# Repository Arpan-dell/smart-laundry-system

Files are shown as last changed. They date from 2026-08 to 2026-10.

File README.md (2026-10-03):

# Smart Laundry Auto-Ordering System

An ESP32-based smart laundry basket that weighs your laundry and automatically sends a pickup order to the laundry manager over Telegram once the basket is full.

> **Status: Phase 1 (working prototype).** The core loop works end to end: weigh, display, auto-order and remind. Planned Phase 2 improvements are listed under [Roadmap](#roadmap-phase-2).

## How It Works

1. **Weighing:** a load cell under the basket, read through an HX711 amplifier, measures the weight of the laundry continuously. Readings are smoothed so the display stays steady but still reacts instantly to large changes.
2. **Display:** a 0.96" SSD1306 OLED shows the live weight, a progress bar towards the target weight, the Wi-Fi signal and the battery level.
3. **Auto-order:** when the weight stays at or above the target (default **5 kg**) for **3 seconds**, the ESP32 sends a pickup request to the laundry manager's Telegram chat:
   ```
   Smart Laundry Alert
   Order ID: #ORD-12345
   Total Weight: 5.12 kg
   Request Time: 04-Oct-2026 06:30 PM
   Pickup Address: <your address>
   ```
   The 3-second hold stops a quick bump or press on the lid from triggering an order.
4. **One order per load:** after an order is sent, the system latches so it doesn't send again. If the basket is still full **24 hours** later, it sends a single `[REMINDER]` message.
5. **Reset:** when the basket is emptied (under 1 kg for 5 seconds), the latch resets, ready for the next load.
6. **Local alert:** a red LED blinks whenever the weight is over the target.

### Boot sequence

On power-up the device shows a splash screen, reconnects to the last Wi-Fi network it joined (12-second timeout), syncs the clock over NTP (IST) so orders carry a real timestamp, then wakes and zeroes the load cell. If Wi-Fi fails, the scale and menu still work offline.

### On-device menu

Press **OK** on the main screen to open the menu. Use **UP/DOWN** to move and **OK** to select.

| Menu item | What it does |
|---|---|
| Tare Scale | Zeroes the scale (empty basket) |
| Set Target | Changes the order threshold in 0.5 kg steps |
| Customer Order | Sends a pickup order manually, with confirmation |
| Calibrate Scale | Two-step calibration: empty the basket and press OK, then place a known weight, set its value with UP/DOWN and press OK. The result is saved to flash |
| Scan WiFi | Scans for nearby networks and connects to the one you pick (see below) |
| Battery Info | Shows the battery percentage |
| Exit Menu | Returns to the main screen |

### Wi-Fi scanning

**Scan WiFi** lists the networks in range. You can connect to:
- any **open** network, or
- any **secured** network whose password is saved in the firmware's `KNOWN_NETWORKS` list.

Secured networks without a saved password are marked with `*`. The ESP32 remembers the last network it joined and reconnects to it on the next boot.

## Engineering Notes

Problems solved while building Phase 1:

- **Wi-Fi start-up resets:** Wi-Fi start-up draws a burst of current that sagged the battery rail and tripped the ESP32's brownout reset. The firmware disables the brownout detector and powers up peripherals in stages.
- **Late HX711 wake-up:** at low supply voltage the HX711 sometimes isn't ready at boot, so it can't be zeroed. The firmware remembers that it still needs zeroing and does it the moment the sensor responds, so a large fake weight never appears.
- **Button-press spikes:** pressing a button on the enclosure physically loads the scale. Weight updates pause for 1.5 seconds after menu actions, so a press can't cause a false reading or an accidental order.
- **Stable readings:** exponential smoothing removes jitter, large changes (basket lifted or loaded) snap through instantly, and anything under 50 g reads as 0.00 kg.
- **Button debouncing:** edge detection plus a 250 ms lockout on each button stops a single press registering twice.

## Hardware

| Component | Purpose |
|---|---|
| ESP32 Dev Board | Main controller, Wi-Fi |
| Load Cell (5/10 kg) + HX711 | Weight sensing |
| 0.96" SSD1306 OLED (I2C) | Live weight and menu UI |
| 3 × Tactile Buttons | UP / OK / DOWN navigation |
| Red LED | Over-target indicator |
| 3.7 V Li-ion + TP4056 (or USB power) | Power |
| 3D-printed enclosure | Designed in Tinkercad (see [`cad/`](cad/)) |

Full pinout and wiring: [`circuit/wiring.md`](circuit/wiring.md). Block diagram: [`circuit/block_diagram.md`](circuit/block_diagram.md).

## Repository Structure

| Folder | Contents |
|---|---|
| [`code/laundry_system/`](code/laundry_system/) | ESP32 firmware (`laundry_system.ino`, `secrets.example.h`) |
| [`circuit/`](circuit/) | Circuit diagram, wiring table, block diagram |
| [`cad/`](cad/) | Enclosure STL files and renders |
| [`photos/`](photos/) | Photos of the build |
| [`videos/`](videos/) | Demo videos |

## Getting Started

1. Wire the components as described in [`circuit/wiring.md`](circuit/wiring.md).
2. In the Arduino IDE, install the libraries **HX711**, **Adafruit SSD1306** and **Adafruit GFX**. (WiFi and HTTPClient come with the ESP32 board package.)
3. In [`code/laundry_system/`](code/laundry_system/), **fill in your own details**:
   - Copy `secrets.example.h` to `secrets.h` and set the Telegram bot token (from @BotFather), the laundry manager's chat ID and the pickup address. `secrets.h` is git-ignored.
   - In `laundry_system.ino`, add your Wi-Fi networks to `KNOWN_NETWORKS`:
     ```cpp
     const KnownNetwork KNOWN_NETWORKS[] = {
       {"YOUR_WIFI_SSID_1", "YOUR_WIFI_PASSWORD_1"},
       {"YOUR_WIFI_SSID_2", "YOUR_WIFI_PASSWORD_2"}
     };
     ```
   > Never commit your real credentials to a public repository.
4. Open `laundry_system.ino` in the Arduino IDE, select your ESP32 board and port, and upload.
5. On the device, use **Scan WiFi** to join a network, then **Calibrate Scale** with a known weight.

## Gallery

### Photos

| | |
|---|---|
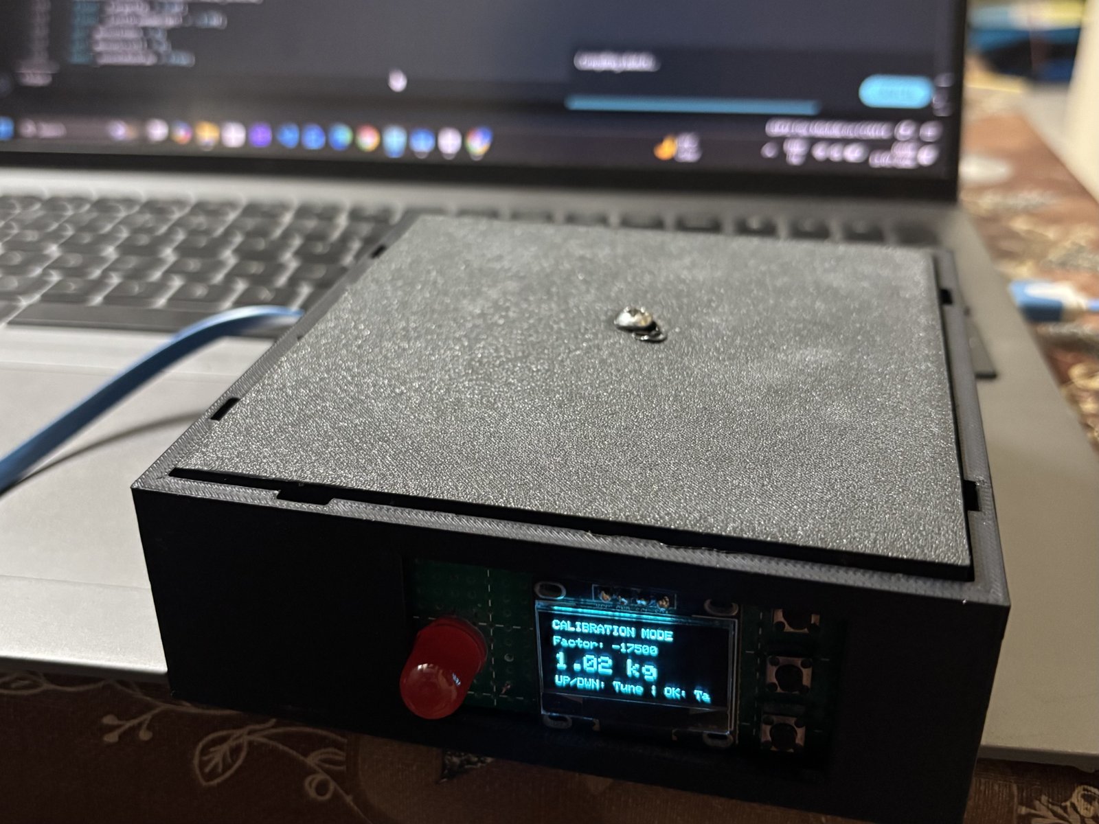
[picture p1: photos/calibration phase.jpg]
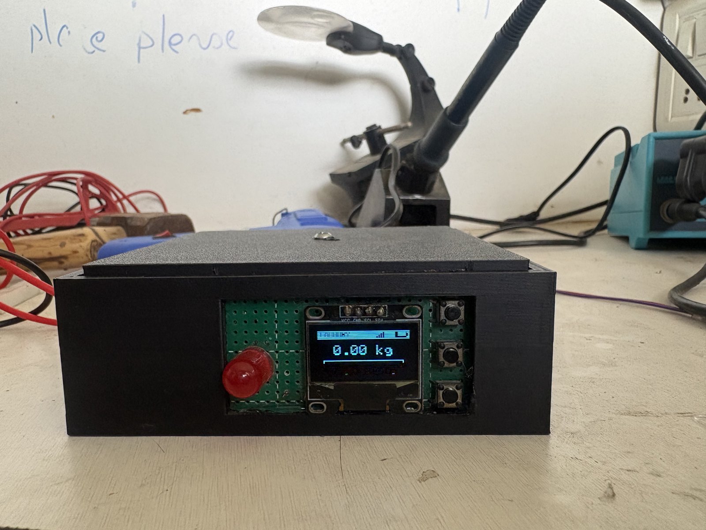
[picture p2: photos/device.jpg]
| <br>**calibration phase** | <br>**device** |
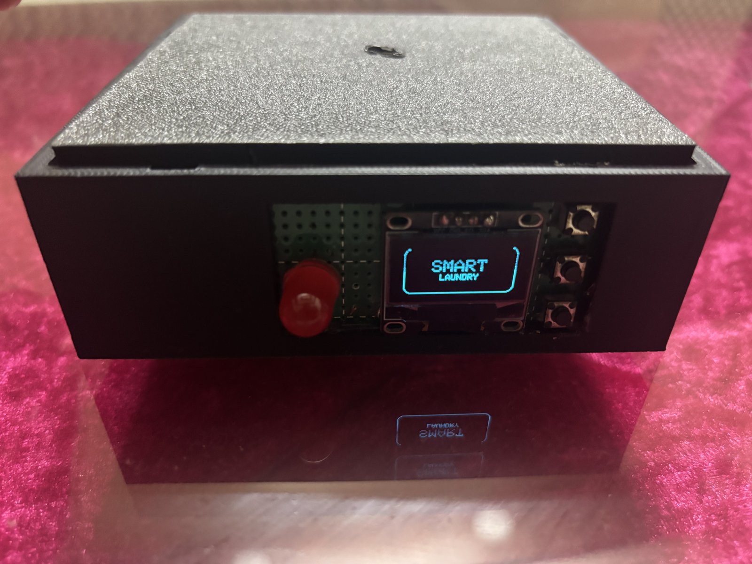
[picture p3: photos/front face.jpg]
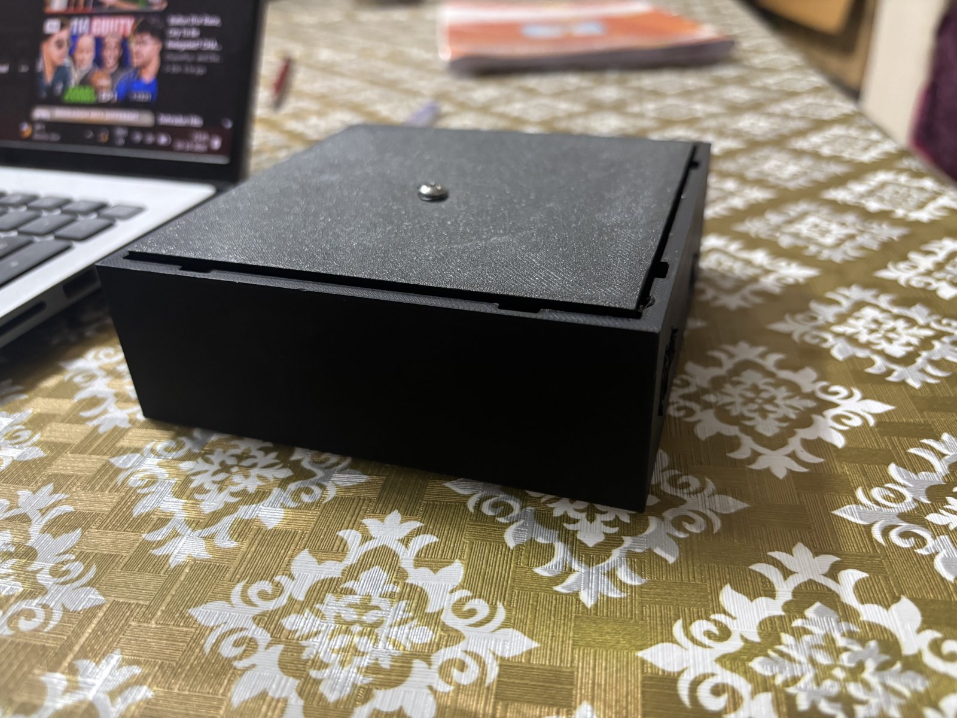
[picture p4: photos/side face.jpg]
| <br>**front face** | <br>**side face** |

### Videos

- [connecting to wifi](videos/connecting%20to%20wifi.mp4)
- [custom order](videos/custom%20order.mp4)
- [menu](videos/menu.mp4)
- [weight verification](videos/weight%20verification.mp4)

## Roadmap (Phase 2)

- [ ] Enter Wi-Fi passwords from a phone (captive portal) instead of saving them in the firmware
- [ ] Save the target weight to flash so it survives a reboot
- [ ] Deep sleep with button/timer wake-up for longer battery life
- [ ] Accurate battery measurement through a calibrated voltage divider
- [ ] Two-way Telegram: confirm or cancel an order from the phone
- [ ] Verified TLS for API calls
- [ ] Custom PCB to replace the perfboard

## Author

**Arpan Ailawadi**
B.Tech, Electronics and Communication Engineering, Delhi Technological University
[LinkedIn](https://www.linkedin.com/in/arpan-ailawadi/)

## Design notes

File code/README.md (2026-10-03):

# Firmware

ESP32 firmware for the Smart Laundry Auto-Ordering System, developed in the Arduino IDE.

## Files

| File | Description |
|---|---|
| `laundry_system/laundry_system.ino` | Main firmware: OLED menu UI, HX711 weighing and calibration, Wi-Fi scanning, threshold auto-orders and Telegram/NTP |
| `laundry_system/secrets.example.h` | Template for the Telegram token, chat ID and pickup address |

## Setup

1. Copy `laundry_system/secrets.example.h` to `laundry_system/secrets.h` and fill in your values (`secrets.h` is git-ignored).
2. Add your Wi-Fi networks to `KNOWN_NETWORKS` at the top of `laundry_system.ino`.
3. Install the required libraries: HX711, Adafruit SSD1306 and Adafruit GFX. WiFi, HTTPClient and Preferences come with the ESP32 board package.
4. Open `laundry_system/laundry_system.ino` in the Arduino IDE, select your ESP32 board and port, then upload.

See [`../circuit/wiring.md`](../circuit/wiring.md) for pin connections.

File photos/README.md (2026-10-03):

# Photos

- [calibration phase](calibration%20phase.jpg)
- [device](device.jpg)
- [front face](front%20face.jpg)
- [side face](side%20face.jpg)

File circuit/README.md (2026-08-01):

# Circuit Documentation

Wiring schematic and system architecture for the Smart Laundry Auto-Ordering System.

## Files

| File | Description |
|---|---|
| `wiring.md` | Full pinout table and step-by-step wiring instructions for the ESP32, HX711 load cell, SSD1306 OLED, and tactile buttons |
| `block_diagram.md` | System block diagram (Mermaid flowchart) showing power, sensing, input, output, and connectivity paths |
| `circuit_diagram.png` | Visual circuit diagram |

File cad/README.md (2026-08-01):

# Enclosure CAD Files

3D-printable enclosure for the Smart Laundry Auto-Ordering System, designed in Tinkercad. The enclosure is split into two printable halves.

## Files

| Folder | Contents | Description |
|---|---|---|
| `bottom/` | `bottom.stl`, `bottom_render1.png`, `bottom_render2.png` | Bottom half of the enclosure — houses the ESP32, HX711, and load cell mount |
| `top/` | `top.stl`, `top_render.png` | Top half of the enclosure — cutouts for the OLED display window and tactile buttons |

## Notes

- Files are provided in `.stl` format, ready for slicing and 3D printing.
- Renders (`.png`) show the design from Tinkercad for quick preview without opening a CAD tool.
- Designed in [Tinkercad](https://www.tinkercad.com/).

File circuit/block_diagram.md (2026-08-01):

# System Block Diagram

```mermaid
flowchart TD
    subgraph Power["Power Supply"]
        BAT["3.7V Li-ion Battery"] --> TP["TP4056 Charger"]
        TP --> ESP32
        USB["USB Power Bank"] -.-> ESP32
    end

    subgraph Sensing["Sensing"]
        LC["Load Cell (5kg/10kg)"] --> HX["HX711 Amplifier"]
        HX -->|DOUT / SCK| ESP32
    end

    subgraph Input["User Input"]
        UP["UP Button"] --> ESP32
        OK["OK Button"] --> ESP32
        DOWN["DOWN Button"] --> ESP32
    end

    ESP32["ESP32 Dev Board"]

    subgraph Output["Display & Alerts"]
        ESP32 -->|I2C: SDA/SCL| OLED["SSD1306 OLED Display"]
        ESP32 -->|Optional| LED["Red LED"]
    end

    subgraph Connectivity["Connectivity"]
        ESP32 -->|Wi-Fi| WIFI["Wi-Fi Network"]
        WIFI --> NTP["NTP Time Sync"]
        WIFI --> TG["Telegram Bot API"]
        TG --> USER["User's Phone (Alert)"]
    end
```

## How it works

1. **Power** — the battery feeds the ESP32 through the TP4056 charger (or USB power directly).
2. **Sensing** — the load cell measures weight, and the HX711 amplifies and digitizes that reading for the ESP32.
3. **Input** — three tactile buttons let the user navigate the on-device menu.
4. **Output** — the ESP32 drives the OLED display for status/menu, and optionally triggers a red LED for local alerts.
5. **Connectivity** — when the weight crosses a threshold, the ESP32 connects to Wi-Fi, syncs time via NTP, and sends a Telegram alert to the user's phone.

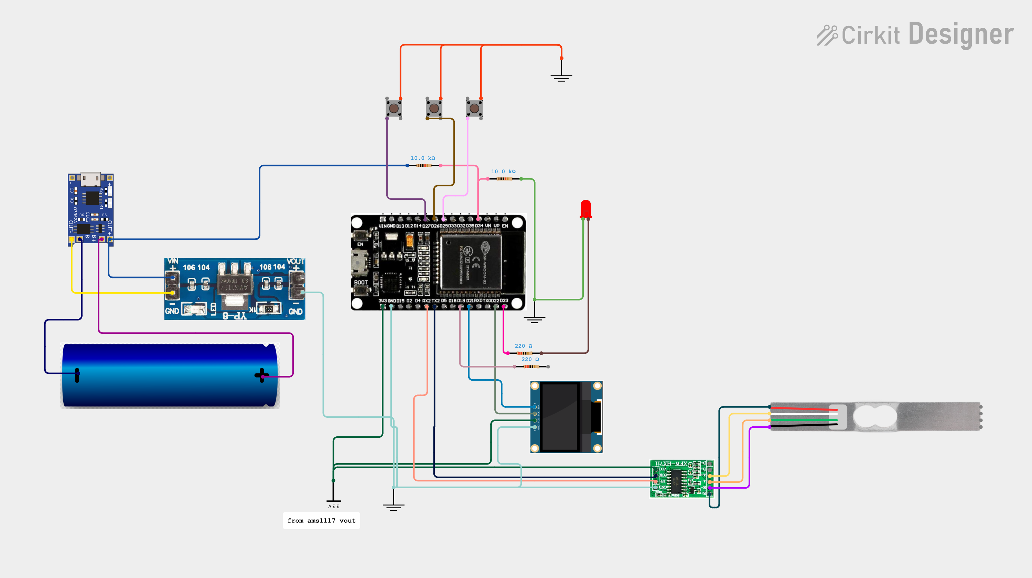
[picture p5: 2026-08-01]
circuit_diagram.png

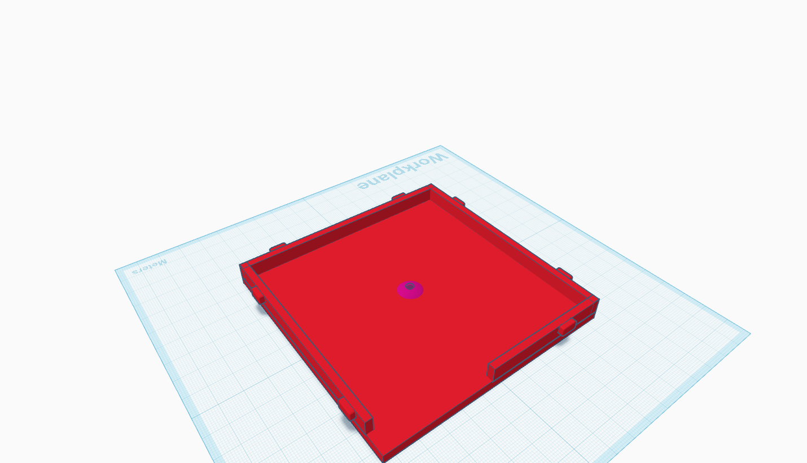
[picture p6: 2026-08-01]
cad/top/top_render.png

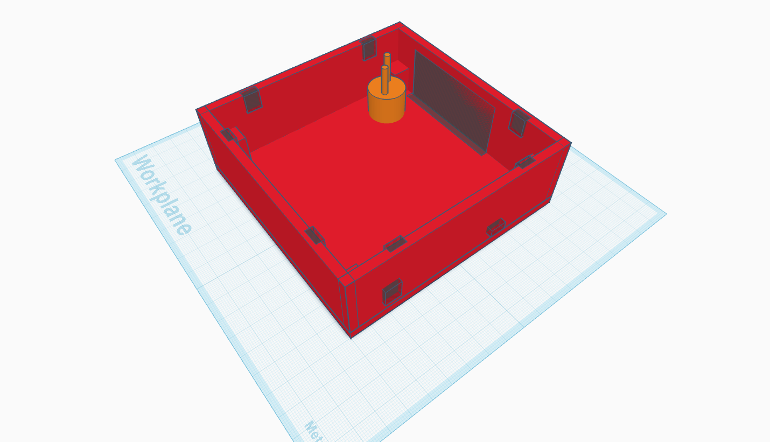
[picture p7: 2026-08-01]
cad/bottom/bottom_render2.png

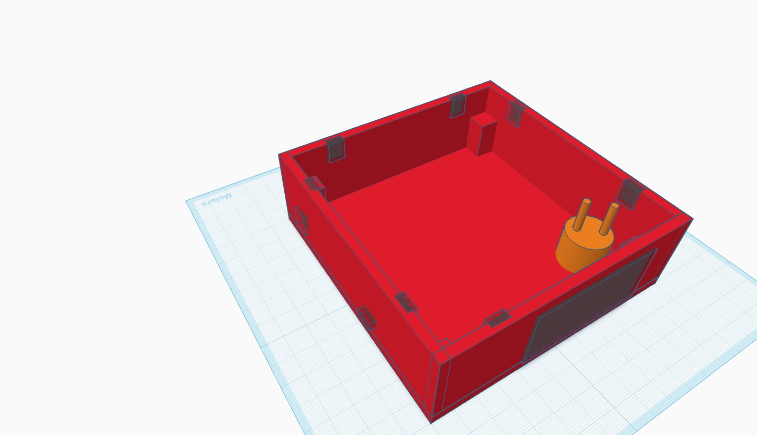
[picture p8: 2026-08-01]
cad/bottom/bottom_render1.png

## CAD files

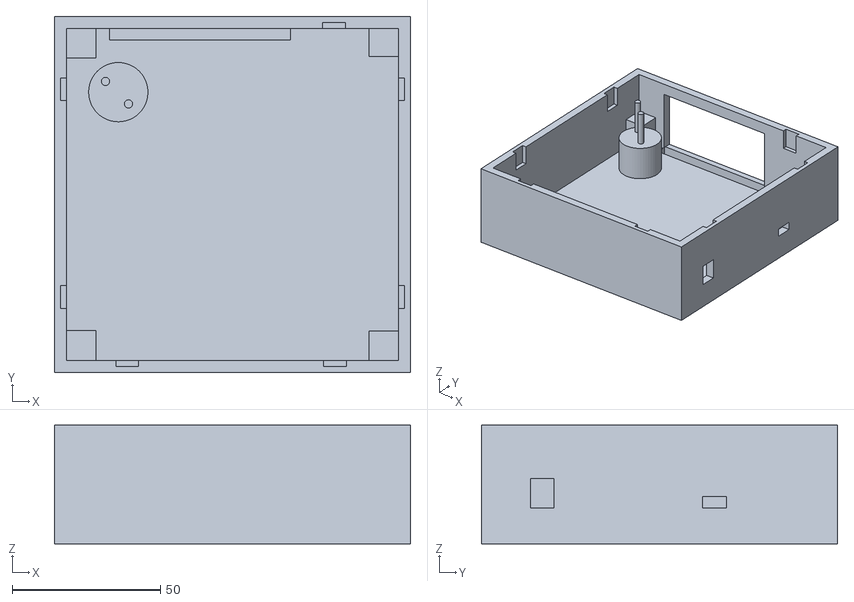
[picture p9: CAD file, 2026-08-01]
cad/bottom/bottom.stl
120.0 x 120.0 x 40.0

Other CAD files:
cad/top/top.stl

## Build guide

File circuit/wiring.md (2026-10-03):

# Wiring / Pin Connections

Complete wiring schematic and component list for the Smart Laundry Auto-Ordering System.

## Components

| Component | Spec |
|---|---|
| Microcontroller | ESP32 Development Board |
| Display | 0.96" SSD1306 OLED (I2C) |
| Weight Sensor | 5kg/10kg Load Cell + HX711 Amplifier |
| Input | 3x Tactile Push Buttons (UP, OK, DOWN) |
| Power Source | 3.7V Lithium Battery via TP4056 Charger (or USB Power Bank) |
| Optional Alert | Red LED |

## Master Pinout Table

| ESP32 Pin | Component | Description / Function |
|---|---|---|
| VIN (or 5V) | Power Source | Connects to Battery OUT+ (via TP4056) or USB power |
| 3V3 | OLED & HX711 | Powers OLED VCC and HX711 VCC (3.3V out) |
| GND | All Components | Common ground for the entire circuit |
| D21 | OLED (SDA) | I2C serial data for the display |
| D22 | OLED (SCL) | I2C serial clock for the display |
| D32 | HX711 (DOUT) | Serial data from the load cell amplifier |
| D33 | HX711 (SCK) | Serial clock to pulse the load cell amplifier |
| D25 | Button (UP) | Tactile button, wired to GND, internal pull-up |
| D26 | Button (OK) | Tactile button, wired to GND, internal pull-up |
| D27 | Button (DOWN) | Tactile button, wired to GND, internal pull-up |
| D34 | Battery Sensor | Reads battery voltage (requires 10k/10k voltage divider) |
| D23 | LED (Optional) | Triggers red threshold warning LED |

## Wiring Instructions

### 1. Power Distribution
- TP4056 `OUT+` → ESP32 `VIN` (or `5V`)
- TP4056 `OUT-` → ESP32 `GND`
- ESP32 `3V3` → OLED `VCC` and HX711 `VCC`/`VDD`

> **Note:** If using the "direct bypass" approach due to a weak battery, the OLED VCC, HX711 VCC, and ESP32 3V3 are all wired directly to TP4056 `OUT+`.

### 2. HX711 Load Cell Amplifier
- `VCC`/`VDD` → ESP32 `3V3`
- `GND` → ESP32 `GND`
- `DOUT` → ESP32 `D32`
- `SCK` → ESP32 `D33`
- Load cell 4-wire (Red, Black, White, Green) → HX711 `E+`, `E-`, `A-`, `A+` respectively

### 3. SSD1306 OLED Display
- `VCC` → ESP32 `3V3`
- `GND` → ESP32 `GND`
- `SDA` → ESP32 `D21`
- `SCL` → ESP32 `D22`

### 4. Push Buttons (Menu Controls)
- **UP:** one leg → `D25`, other leg → `GND`
- **OK:** one leg → `D26`, other leg → `GND`
- **DOWN:** one leg → `D27`, other leg → `GND`

No external resistors needed — firmware enables the ESP32's internal pull-up resistors.

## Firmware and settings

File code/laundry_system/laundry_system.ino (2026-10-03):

// ============================================================================
// SMART LAUNDRY AUTO-ORDERING SYSTEM - Phase 1
// Weighs the laundry basket with an HX711 load cell, shows live weight and a
// 3-button menu on an SSD1306 OLED, and sends a pickup order to the laundry
// manager on Telegram once the basket stays above the target weight.
// ============================================================================

#include <WiFi.h>
#include "secrets.h" // tokens, passwords, private URLs: copy secrets.example.h to secrets.h
#include <Wire.h>
#include <Adafruit_GFX.h>
#include <Adafruit_SSD1306.h>
#include "HX711.h"
#include <Preferences.h>
#include "soc/soc.h"
#include "soc/rtc_cntl_reg.h"

// ---------------- Config ----------------
#define REMINDER_DELAY_MS  86400000UL // 24 hours before reminder is sent

// >>> FILL THESE IN FOR YOUR OWN SETUP before uploading <<<
// Wi-Fi networks the device may join from the "Scan WiFi" menu.
// Open networks need no entry; secured networks must be listed here.
// Telegram token, chat ID and pickup address go in secrets.h
// (copy secrets.example.h to secrets.h). Never commit real values.
struct KnownNetwork {
  const char* ssid;
  const char* pass;
};
const KnownNetwork KNOWN_NETWORKS[] = {
  {"YOUR_WIFI_SSID_1", "YOUR_WIFI_PASSWORD_1"},
  {"YOUR_WIFI_SSID_2", "YOUR_WIFI_PASSWORD_2"}
};
const int NUM_KNOWN_NETWORKS = sizeof(KNOWN_NETWORKS) / sizeof(KnownNetwork);

#define NTP_SERVER          "pool.ntp.org"
#define GMT_OFFSET_SEC       (5 * 3600 + 1800)  
#define DAYLIGHT_OFFSET_SEC  0
#define SCREEN_WIDTH  128
#define SCREEN_HEIGHT 64
#define OLED_RESET    -1
#define I2C_SDA       21
#define I2C_SCL       22
#define OLED_I2C_ADDR 0x3C

#define LOADCELL_DOUT_PIN 32
#define LOADCELL_SCK_PIN  33
#define LOADCELL_CALIBRATION_FACTOR -30616.0f

#define BTN_UP_PIN   25
#define BTN_OK_PIN   26
#define BTN_DOWN_PIN 27

#define BATT_PIN     34
#define BATT_RAW_MIN 1980
#define BATT_RAW_MAX 2600

#define LED_RED_PIN 23   

#define DEFAULT_TARGET_KG 5.0f

class ButtonManager {
public:
  struct Presses {
    bool up, ok, down;
    bool any() const { return up || ok || down; }
  };

  void begin(uint8_t upPin, uint8_t okPin, uint8_t downPin) {
    _upPin = upPin;
    _okPin = okPin;
    _downPin = downPin;
    pinMode(_upPin, INPUT_PULLUP);
    pinMode(_okPin, INPUT_PULLUP);
    pinMode(_downPin, INPUT_PULLUP);
  }

  Presses poll() {
    Presses p = {false, false, false};
    unsigned long now = millis();

    // Check UP (250ms debounce to prevent double-clicks from cheap springs)
    bool upState = digitalRead(_upPin) == LOW;
    if (upState && !_lastUpState && now - _lastUpTime > 250) {
      p.up = true; _lastUpTime = now;
    }
    _lastUpState = upState;

    // Check OK
    bool okState = digitalRead(_okPin) == LOW;
    if (okState && !_lastOkState && now - _lastOkTime > 250) {
      p.ok = true; _lastOkTime = now;
    }
    _lastOkState = okState;

    // Check DOWN
    bool downState = digitalRead(_downPin) == LOW;
    if (downState && !_lastDownState && now - _lastDownTime > 250) {
      p.down = true; _lastDownTime = now;
    }
    _lastDownState = downState;

    return p;
  }

private:
  uint8_t _upPin = 0, _okPin = 0, _downPin = 0;
  bool _lastUpState = false, _lastOkState = false, _lastDownState = false;
  unsigned long _lastUpTime = 0, _lastOkTime = 0, _lastDownTime = 0;
};


// ---------------- BatteryMonitor ----------------
class BatteryMonitor {
public:
  void begin(uint8_t pin) { 
    _pin = pin; 
    _smoothedPct = -1; 
  }
  
  int readPercentage() {
    // Take an average of 20 samples to filter out Wi-Fi electrical noise
    long sum = 0;
    for (int i = 0; i < 20; i++) {
      sum += analogRead(_pin);
    }
    int raw = sum / 20;
    
    int pct = map(raw, BATT_RAW_MIN, BATT_RAW_MAX, 0, 100);
    pct = constrain(pct, 0, 100);
    
    // Smooth the percentage so it doesn't jump randomly between redraws
    if (_smoothedPct == -1) {
      _smoothedPct = pct;
    } else {
      _smoothedPct = (_smoothedPct * 9 + pct) / 10;
    }
    
    return _smoothedPct;
  }
private:
  uint8_t _pin = 0;
  int _smoothedPct = -1;
};


// ---------------- DisplayManager ----------------
class DisplayManager {
public:
  bool begin() {
    Wire.begin(I2C_SDA, I2C_SCL);
    bool ok = _display.begin(SSD1306_SWITCHCAPVCC, OLED_I2C_ADDR);
    if (!ok) {
      delay(500);
      ok = _display.begin(SSD1306_SWITCHCAPVCC, OLED_I2C_ADDR);
    }
    Wire.setClock(100000);
    _display.setTextColor(SSD1306_WHITE);
    _display.cp437(true);
    return ok;
  }

  void showBootScreen(const char* title, const char* subtitle) {
    _display.clearDisplay();
    _display.drawRoundRect(4, 4, SCREEN_WIDTH - 8, SCREEN_HEIGHT - 8, 8, SSD1306_WHITE);
    printCentered(title, 18, 2);
    printCentered(subtitle, 36, 1);
    _display.display();
  }

  void showStatusLine(const char* line1, const char* line2, int dots) {
    _display.clearDisplay();
    printCentered(line1, 10, 1);
    printCentered(line2, 22, 1);
    for (int i = 0; i < dots && i < 6; i++) {
      _display.setCursor(10 + i * 8, 40);
      _display.print(".");
    }
    _display.display();
  }

  void showToast(const char* msg, uint16_t holdMs = 800) {
    _display.clearDisplay();
    printCentered(msg, 24, 2);
    _display.display();
    delay(holdMs);
  }

  void drawMainScreen(float weightKg, float targetKg, int batteryPct, int wifiBars) {
    _display.clearDisplay();
    drawHeader(batteryPct, wifiBars);
    char buf[16];
    dtostrf(weightKg, 4, 2, buf);
    String weightStr = String(buf) + " kg";
    printCentered(weightStr.c_str(), 20, 2);
    drawTargetBar(weightKg, targetKg, 42, 10);
    _display.display();
  }

  void drawMenuList(const char* const* items, int count, int selectedIndex, int scrollOffset) {
    _display.clearDisplay();
    printCentered("MENU", 0, 1);
    _display.drawLine(0, 10, SCREEN_WIDTH, 10, SSD1306_WHITE);

    const int visibleRows = 3;
    for (int row = 0; row < visibleRows; row++) {
      int itemIdx = scrollOffset + row;
      if (itemIdx >= count) break;
      int y = 14 + row * 16;
      bool selected = (itemIdx == selectedIndex);

      if (selected) {
        _display.fillRect(0, y - 1, SCREEN_WIDTH, 14, SSD1306_WHITE);
        _display.setTextColor(SSD1306_BLACK);
      } else {
        _display.setTextColor(SSD1306_WHITE);
      }
      _display.setTextSize(1);
      _display.setCursor(6, y + 3);
      _display.print(items[itemIdx]);
    }
    _display.setTextColor(SSD1306_WHITE);
    _display.display();
  }

  void drawEditThreshold(float targetKg) {
    _display.clearDisplay();
    printCentered("SET TARGET", 2, 1);
    char buf[16];
    dtostrf(targetKg, 4, 2, buf);
    String s = String(buf) + " kg";
    printCentered(s.c_str(), 20, 2);
    printCentered("UP/DOWN +-0.5", 44, 1);
    printCentered("OK = Save", 54, 1);   
    _display.display();
  }

  void drawBatteryInfo(int pct) {
    _display.clearDisplay();
    printCentered("BATTERY", 2, 1);
    drawBattery(56, 18, pct, SSD1306_WHITE);
    char buf[8];
    snprintf(buf, sizeof(buf), "%d%%", pct);
    printCentered(buf, 32, 2);
    printCentered("OK = Back", 54, 1);   
    _display.display();
  }

  void drawConfirmOrder() {
    _display.clearDisplay();
    printCentered("ORDER PICKUP?", 6, 1);
    printCentered("OK = Confirm", 28, 1);
    printCentered("UP/DOWN = Cancel", 42, 1);
    _display.display();
  }

  void drawWifiScanner(int numNetworks, int selectedIndex, int scrollOffset) {
    _display.clearDisplay();
    printCentered("SELECT WIFI", 0, 1);
    _display.drawLine(0, 10, SCREEN_WIDTH, 10, SSD1306_WHITE);

    if (numNetworks == -1) {
      printCentered("Scanning...", 30, 1);
    } else {
      int totalItems = (numNetworks == 0) ? 1 : numNetworks + 1;
      const int visibleRows = 3;
      for (int row = 0; row < visibleRows; row++) {
        int itemIdx = scrollOffset + row;
        if (itemIdx >= totalItems) break;
        int y = 14 + row * 16;
        bool selected = (itemIdx == selectedIndex);

        if (selected) {
          _display.fillRect(0, y - 1, SCREEN_WIDTH, 14, SSD1306_WHITE);
          _display.setTextColor(SSD1306_BLACK);
        } else {
          _display.setTextColor(SSD1306_WHITE);
        }
        _display.setTextSize(1);
        _display.setCursor(6, y + 3);
        
        if (numNetworks == 0 && itemIdx == 0) {
           _display.print("[ No WiFi - Back ]");
        } else if (itemIdx == numNetworks) {
           _display.print("[ Cancel & Back ]");
        } else {
           String ssid = WiFi.SSID(itemIdx);
           if (ssid.length() > 18) ssid = ssid.substring(0, 18);
           _display.print(ssid);
           
           if (WiFi.encryptionType(itemIdx) != WIFI_AUTH_OPEN) {
             bool isSaved = false;
             for (int i = 0; i < NUM_KNOWN_NETWORKS; i++) {
               if (ssid == KNOWN_NETWORKS[i].ssid) {
                 isSaved = true;
                 break;
               }
             }
             if (!isSaved) {
               _display.setCursor(SCREEN_WIDTH - 10, y + 3);
               _display.print("*");
             }
           }
        }
      }
    }
    _display.setTextColor(SSD1306_WHITE);
    _display.display();
  }

  void drawCalibrateEmpty() {
    _display.clearDisplay();
    printCentered("CALIBRATION", 0, 1);
    printCentered("1. Empty Basket", 20, 1);
    printCentered("Then Press OK", 36, 1);
    _display.display();
  }

  void drawCalibrateWeight(float knownWeight) {
    _display.clearDisplay();
    printCentered("CALIBRATION", 0, 1);
    printCentered("2. Place Weight", 12, 1);
    
    char buf[16];
    dtostrf(knownWeight, 4, 2, buf);
    String s = String(buf) + " kg";
    printCentered(s.c_str(), 28, 2);
    
    printCentered("UP/DOWN to edit", 46, 1);
    printCentered("OK to save", 56, 1);
    _display.display();
  }

private:
  Adafruit_SSD1306 _display{SCREEN_WIDTH, SCREEN_HEIGHT, &Wire, OLED_RESET};

  void printCentered(const char* text, int y, int size) {
    _display.setTextSize(size);
    int16_t x1, y1;
    uint16_t w, h;
    _display.getTextBounds(text, 0, y, &x1, &y1, &w, &h);
    int x = (SCREEN_WIDTH - (int)w) / 2;
    if (x < 0) x = 0;
    _display.setCursor(x, y);
    _display.print(text);
  }

  void drawHeader(int batteryPct, int wifiBars) {
    _display.fillRect(0, 0, SCREEN_WIDTH, 12, SSD1306_WHITE);
    _display.setTextColor(SSD1306_BLACK);
    _display.setTextSize(1);
    _display.setCursor(4, 2);
    _display.print("LAUNDRY");
    drawWifiBars(SCREEN_WIDTH - 46, 2, wifiBars, SSD1306_BLACK);
    drawBattery(SCREEN_WIDTH - 20, 2, batteryPct, SSD1306_BLACK);
    _display.setTextColor(SSD1306_WHITE);
  }

  void drawBattery(int x, int y, int pct, uint16_t color) {
    _display.drawRect(x, y, 16, 8, color);
    _display.fillRect(x + 16, y + 2, 2, 4, color);
    int fillWidth = map(constrain(pct, 0, 100), 0, 100, 0, 14);
    if (fillWidth > 0) {
      _display.fillRect(x + 1, y + 1, fillWidth, 6, color);
    }
  }

  void drawWifiBars(int x, int y, int wifiBars, uint16_t color) {
    if (wifiBars < 0) {
      _display.drawLine(x, y, x + 8, y + 8, color);
      _display.drawLine(x, y + 8, x + 8, y, color);
      return;
    }
    for (int i = 0; i < 4; i++) {
      int barHeight = 2 + i * 2;
      int barX = x + i * 3;
      int barY = y + 8 - barHeight;
      if (i < wifiBars) {
        _display.fillRect(barX, barY, 2, barHeight, color);
      } else {
        _display.drawRect(barX, barY, 2, barHeight, color);
      }
    }
  }

  void drawTargetBar(float weightKg, float targetKg, int y, int height) {
    int barX = 8;
    int barW = SCREEN_WIDTH - 16;
    _display.drawRect(barX, y, barW, height, SSD1306_WHITE);
    if (targetKg > 0.0f) {
      float ratio = weightKg / targetKg;
      ratio = constrain(ratio, 0.0f, 1.0f);
      int fillW = (int)(ratio * (barW - 2));
      if (fillW > 0) {
        _display.fillRect(barX + 1, y + 1, fillW, height - 2, SSD1306_WHITE);
      }
    }
    char buf[24];
    snprintf(buf, sizeof(buf), "Target: %.2f kg", targetKg);
    int labelY = min(y + height + 2, SCREEN_HEIGHT - 8);
    printCentered(buf, labelY, 1);
  }
};


// ---------------- LoadCellManager ----------------
class LoadCellManager {
public:
  bool begin(unsigned int timeoutMs = 5000) { // Increased to 5 seconds to guarantee boot tare
    // At low voltages (2.6V), the HX711 struggles to wake up from deep sleep.
    // Instead of forcing it to sleep, we just let it stabilize naturally during boot.
    digitalWrite(LOADCELL_SCK_PIN, LOW);
    delay(500);

    _prefs.begin("scale", false);
    _calFactor = _prefs.getFloat("cal", LOADCELL_CALIBRATION_FACTOR);

    _scale.begin(LOADCELL_DOUT_PIN, LOADCELL_SCK_PIN);
    _scale.set_scale(_calFactor);

    unsigned long start = millis();
    while (millis() - start < timeoutMs) {
      if (_scale.is_ready()) {
        _scale.tare();
        _ready = true;
        _needsTare = false;
        return true;
      }
      delay(10);
    }
    _ready = false;
    _needsTare = true; // Mark that we STILL need to tare when it finally wakes up!
    return false;
  }

  bool calibrate(float knownWeightKg, unsigned int timeoutMs = 5000) {
    if (knownWeightKg <= 0.0f) return false;
    unsigned long start = millis();
    while (millis() - start < timeoutMs) {
      if (_scale.is_ready()) {
        long val = _scale.get_value(10); // get average of 10 raw readings minus tare offset
        if (val == 0) return false; // Prevent divide by zero
        _calFactor = (float)val / knownWeightKg;
        _scale.set_scale(_calFactor);
        _prefs.putFloat("cal", _calFactor);
        return true;
      }
      delay(10);
    }
    return false;
  }

  bool tare(unsigned int timeoutMs = 2000) {
    unsigned long start = millis();
    while (millis() - start < timeoutMs) {
      if (_scale.is_ready()) {
        _scale.tare();
        _lastWeight = 0.0f;
        _needsTare = false;
        return true;
      }
      delay(10);
    }
    return false;
  }
  bool isReady() { return _scale.is_ready(); }
  void ignoreSpikesFor(unsigned int ms) {
    _ignoreSpikesUntil = millis() + ms;
  }

  float readKg() {
    if (_scale.is_ready()) {
      if (_needsTare) {
        // It finally woke up late! Tare it instantly before reading to prevent a massive fake weight spike.
        _scale.tare();
        _needsTare = false;
        _lastWeight = 0.0f;
        return 0.0f;
      }

      float raw = _scale.get_units(1);
      if (raw < 0.0f) raw = 0.0f;
      
      if (millis() > _ignoreSpikesUntil) {
        // If the weight jumps massively (e.g. basket picked up or dropped), snap to it instantly
        if (abs(raw - _lastWeight) > 1.0f) {
          _lastWeight = raw;
        } else {
          // Otherwise, apply Exponential Moving Average (EMA) smoothing to eliminate tiny jitter
          _lastWeight = (_lastWeight * 0.8f) + (raw * 0.2f);
        }
        
        // Deadband: If the weight is less than 50 grams, force it to 0.0 kg to prevent asymptotic floating point tails
        if (_lastWeight < 0.05f) {
          _lastWeight = 0.0f;
        }
      }
    }
    return _lastWeight;
  }

private:
  HX711 _scale;
  Preferences _prefs;
  float _calFactor = 1.0f;
  bool _ready = false;
  bool _needsTare = true;
  float _lastWeight = 0.0f;
  unsigned long _ignoreSpikesUntil = 0;
};


// ---------------- AlertManager ----------------
class AlertManager {
public:
  void begin() {
    pinMode(LED_RED_PIN, OUTPUT);
    digitalWrite(LED_RED_PIN, LOW);
  }
  void updateThresholdLed(bool overThreshold) {
    digitalWrite(LED_RED_PIN, overThreshold ? ((millis() / 500) % 2) : LOW);
  }
};


// ---------------- LaundryNetwork (Phase 3) ----------------
#include <HTTPClient.h>
#include <WiFiClientSecure.h>

class LaundryNetwork {
public:
  bool isConnected() { return WiFi.status() == WL_CONNECTED; }

  int wifiBars() {
    if (WiFi.status() != WL_CONNECTED) return -1;
    long rssi = WiFi.RSSI();
    if (rssi >= -55) return 4;
    if (rssi >= -65) return 3;
    if (rssi >= -75) return 2;
    if (rssi >= -85) return 1;
    return 0;
  }

  int sendPickupAlert(float weightKg, bool isReminder = false) {
    if (!isConnected()) return -1;

    WiFiClientSecure client;
    client.setInsecure();
    HTTPClient http;

    struct tm timeinfo;
    String timeString = "Time unavailable";
    if (getLocalTime(&timeinfo, 1000)) {
      char buf[32];
      strftime(buf, sizeof(buf), "%d-%b-%Y %I:%M %p", &timeinfo);
      timeString = String(buf);
    }

    uint32_t orderNum = esp_random() % 90000 + 10000;
    String message = isReminder ? "⚠️ [REMINDER] Smart Laundry Alert\n" : "Smart Laundry Alert\n";
    message += "Order ID: #ORD-" + String(orderNum) + "\n";
    message += "Total Weight: " + String(weightKg, 2) + " kg\n";
    message += "Request Time: " + timeString + "\n";
    message += "Pickup Address: " + String(PICKUP_ADDRESS);

    String url = "https://api.telegram.org/bot" + String(TELEGRAM_BOT_TOKEN) +
                 "/sendMessage?chat_id=" + String(TELEGRAM_CHAT_ID) +
                 "&text=" + urlEncode(message);

    http.begin(client, url);
    int code = http.GET();
    http.end();
    return code;
  }

private:
  String urlEncode(const String& s) {
    String out;
    out.reserve(s.length());
    for (size_t i = 0; i < s.length(); i++) {
      char c = s[i];
      if (c == ' ') out += "%20";
      else if (c == '\n') out += "%0A";
      else out += c;
    }
    return out;
  }
};


// ---------------- AppController ----------------
enum class UIState {
  MAIN_SCREEN,
  MENU_LIST,
  EDIT_THRESHOLD,
  BATTERY_INFO,
  CONFIRM_ORDER,
  WIFI_SCANNER,
  CALIBRATE_EMPTY,
  CALIBRATE_WEIGHT
};

class AppController {
public:
  using TareFn  = void  (*)();
  using OrderFn = void  (*)(bool);
  using FloatFn = float (*)();
  using IntFn   = int   (*)();
  using IgnoreSpikesFn = void (*)(unsigned int);
  using VoidFn  = void  (*)();
  using ConnectNetworkFn = void (*)(int);
  using CalibrateFn = bool (*)(float);

  void begin(DisplayManager* display, ButtonManager* buttons,
             TareFn tareFn, OrderFn orderFn,
             FloatFn getWeightFn, IntFn getBatteryFn, IntFn getWifiBarsFn,
             IgnoreSpikesFn ignoreSpikesFn, VoidFn scanWifiFn, ConnectNetworkFn connectNetworkFn,
             CalibrateFn calibrateFn, float initialTargetKg) {
    _display = display;
    _buttons = buttons;
    _tareFn = tareFn;
    _orderFn = orderFn;
    _getWeightFn = getWeightFn;
    _scanWifiFn = scanWifiFn;
    _connectNetworkFn = connectNetworkFn;
    _calibrateFn = calibrateFn;
    _getBatteryFn = getBatteryFn;
    _getWifiBarsFn = getWifiBarsFn;
    _ignoreSpikesFn = ignoreSpikesFn;
    _targetKg = initialTargetKg;
    _needsRedraw = true;
  }

  float targetKg() const { return _targetKg; }

  void update() {
    ButtonManager::Presses p = _buttons->poll();
    UIState prevState = _state;

    if (p.any()) {
      handleInput(p);
      _needsRedraw = true;
    }

    // FIX: only (re-)arm the anti-jitter freeze on an actual transition into
    // a menu screen, or on a press while already on the main screen - not
    // every single loop tick. Re-arming every tick (the old version) meant
    // the freeze window kept sliding forward for as long as you were
    // anywhere off the main screen, and nothing cleared it on return - so
    // the live weight could sit stuck for a while (or indefinitely, if you
    // kept navigating) even after you were back looking at the main screen.
    if (_ignoreSpikesFn) {
      if (_state != UIState::MAIN_SCREEN && prevState != _state) {
        _ignoreSpikesFn(1500);      // just entered a menu screen - brief freeze
      } else if (_state == UIState::MAIN_SCREEN && prevState != _state) {
        _ignoreSpikesFn(0);         // just returned to main - clear the freeze now
      } else if (p.any() && _state == UIState::MAIN_SCREEN) {
        _ignoreSpikesFn(1500);      // press while already on main - brief freeze
      }
    }

    // Force redraw whenever the weight changes by even 0.01kg so it stays live.
    float currentWeight = _getWeightFn ? _getWeightFn() : 0.0f;
    if (_state == UIState::MAIN_SCREEN && fabs(currentWeight - _lastDrawnWeight) >= 0.01f) {
      _lastDrawnWeight = currentWeight;
      _needsRedraw = true;
    }

    if (_needsRedraw) {
      redraw();
      _needsRedraw = false;
    }
  }
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
void loop() {
  float weight = loadCell.readKg();

  float target = app.targetKg();
  bool overThreshold = (target > 0.0f) && (weight >= target);

  alerts.updateThresholdLed(overThreshold);

  if (overThreshold) {
    if (overThresholdStart == 0) overThresholdStart = millis();
    if (millis() - overThresholdStart > 3000 && !autoOrderLatched) {
      autoOrderLatched = true;
      autoOrderTime = millis();
      doOrder(false); // First order
    }
    
    // Reminder Logic: Wait REMINDER_DELAY_MS after the first order
    if (autoOrderLatched && !reminderSent) {
      if (millis() - autoOrderTime > REMINDER_DELAY_MS) {
        reminderSent = true;
        doOrder(true); // Send Reminder
      }
    }
  } else {
    overThresholdStart = 0;
  }

  if (weight < 1.0f) {
    if (underThresholdStart == 0) underThresholdStart = millis();
    if (millis() - underThresholdStart > 5000 && autoOrderLatched) {
      autoOrderLatched = false;
      reminderSent = false;
    }
  } else {
    underThresholdStart = 0;
  }

  app.update();
  yield();
}

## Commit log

2026-08-01 Add missing firmware code
    [laundry_system.ino]
2026-08-01 Create circuit
2026-08-01 Add wiring table
2026-08-01 Create README.md for Circuit documentation
    Added documentation for the Smart Laundry Auto-Ordering System, including wiring instructions and system architecture.
2026-10-03 Replace credentials with placeholders, rewrite README, remove stale code
    - Config values are now placeholders with fill-in instructions
    - README describes the actual auto-pickup flow, menu and engineering notes
    - Remove stale header comment, temporary debug block and unused buzzer stub
    [laundry_system.ino]
2026-10-03 Upload latest firmware: Wi-Fi scanning and on-device calibration
    - Move firmware to code/laundry_system/ with secrets.example.h; secrets.h is git-ignored
    - Wi-Fi networks are placeholders to fill in (KNOWN_NETWORKS)
    - Wire up button handling for the Calibrate Scale screens
    - Remove stale header comment, debug block and unused buzzer stub
    - Document Scan WiFi, Calibrate Scale and the laundry manager flow in the README
    [laundry_system.ino]
